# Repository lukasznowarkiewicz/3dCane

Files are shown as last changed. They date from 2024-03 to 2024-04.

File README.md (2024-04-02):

# 3dCane

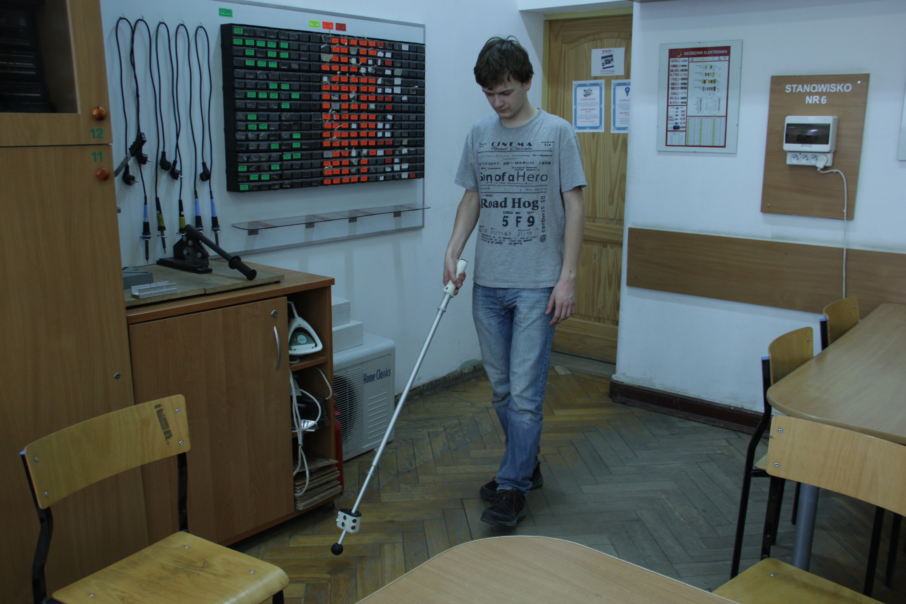
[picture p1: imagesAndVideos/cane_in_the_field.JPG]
3D Cane in the field


## Introduction
In 2017, we, Jacek Martyniak and Łukasz Nowarkiewicz from the Electrical and Electronic School in Szczecin, under the guidance of our mentor with a PhD, Dariusz Mostowski, took on a project for the XVII Innovation and Invention Olympics. Our goal was simple: to design an intelligent electronic cane for the visually impaired and blind. This cane was intended to make navigating both outdoor city environments and indoor spaces easier for them. We focused on ensuring the cane was easy and intuitive to use, with a modular design that could be produced and maintained at a reasonable cost.

## Project assumptions

Our project, 3D.CANE, is built on the foundation of enhancing mobility for the visually impaired through a three-dimensional environmental analysis using a multidirectional ultrasonic scanner. This electronic cane system delivers clear information about potential obstacles and features dual-mode communication (acoustic messages and tactile feedback via vibration) to ensure user safety and convenience. It includes features like fall and assault alarms, time and location updates, and modular design for easy maintenance and upgrades, all while focusing on cost-effective production and user-friendly design.

## Hardware - electronics

The core of the 3D.CANE system is built around two 8-bit AVR ATmega microcontrollers by ATMEL, with the electronic cane module based on an ATmega64 for its advanced capabilities in handling two-way communication with the wrist-worn control module and controlling the ultrasonic scanner module. Essential to the project's functionality, we incorporated various dedicated circuits, including a digital accelerometer (ADXL325), a radio communication module (NRF24L01), vibration motor controllers (BC847 transistors), and distance measuring modules (US-015), all chosen for their reliability and cost-effectiveness. The software was developed in the C language within the Eclipse Indigo environment, emphasizing modular and easily upgradable design.

## Hardware - electronics - 3d.cane 

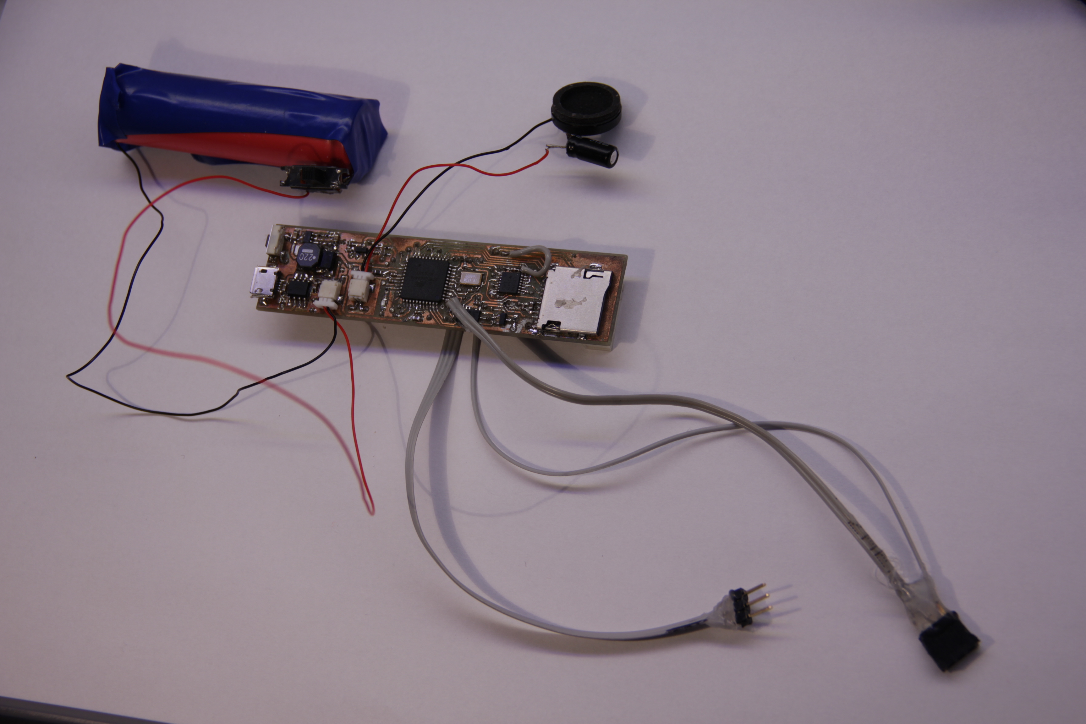
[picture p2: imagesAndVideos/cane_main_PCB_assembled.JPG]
Main PCB Assembled

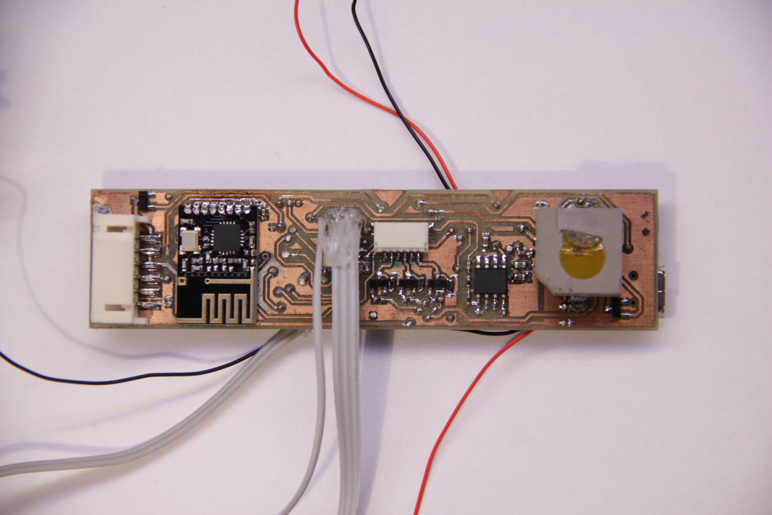
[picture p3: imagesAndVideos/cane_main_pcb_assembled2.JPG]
Main PCB Assembled Alternate View


1. **Power Supply Block:** Utilizes a 3.7V lithium-ion battery type 18650, paired with a compact TP4056 integrated circuit charger, enabling charging via an external adapter through a micro USB port on the handle casing.

2. **Central Processing Unit (CPU):** Heart of the cane, featuring an 8-bit AVR microcontroller by Atmel based on a Reduced Instruction Set Computing (RISC) architecture. This unit, equipped with dual UART interfaces, facilitates programming and communication with the ultrasonic sensors, and possesses picoPower technology for energy efficiency.

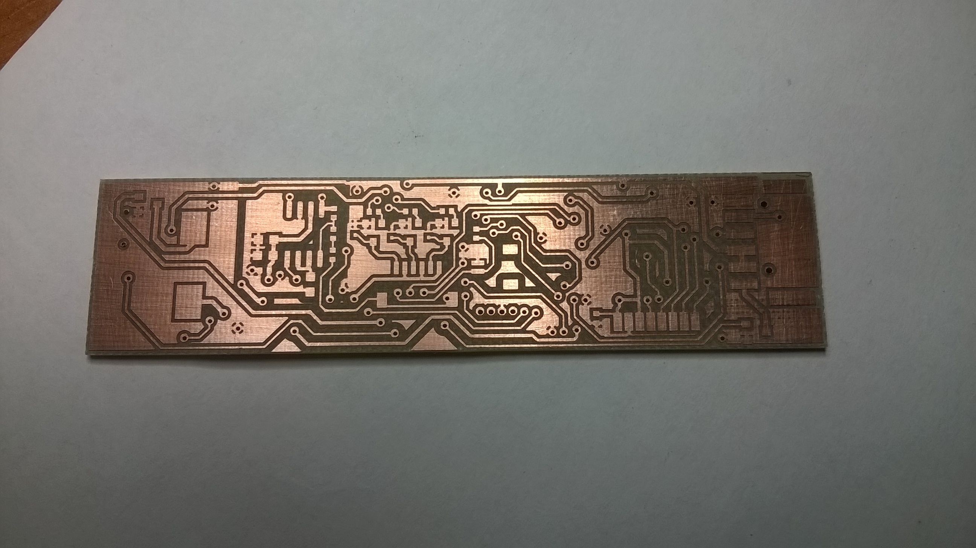
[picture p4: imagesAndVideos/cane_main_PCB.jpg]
Cane Main PCB
   

4. **Ultrasonic Sensor Block:** Employs three US-015 ultrasonic modules for a three-axis environmental scanner, which communicate via trig and echo lines to measure distances using 40 KHz sound waves, and calculates distance based on the time duration of the high state signal.

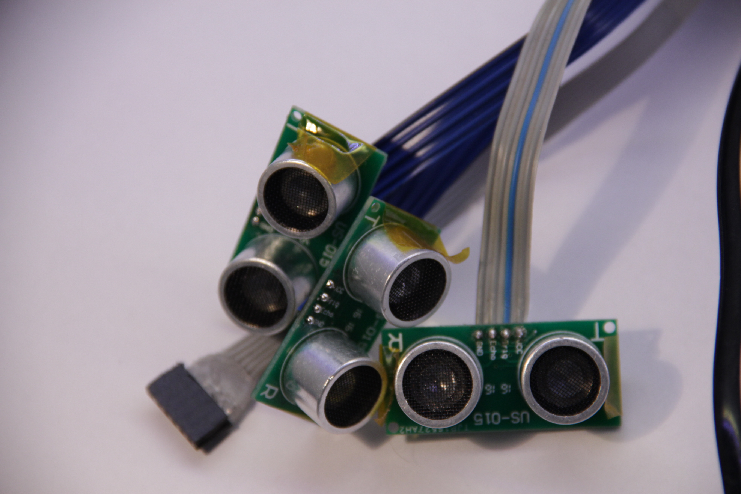
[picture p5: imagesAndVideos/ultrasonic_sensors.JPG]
Ultrasonic Sensors

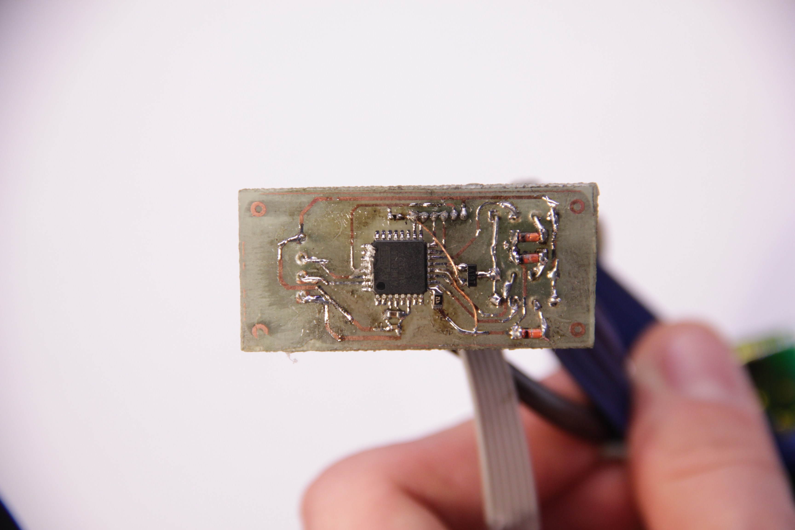
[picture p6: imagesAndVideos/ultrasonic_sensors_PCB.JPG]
Ultrasonic Sensors PCB

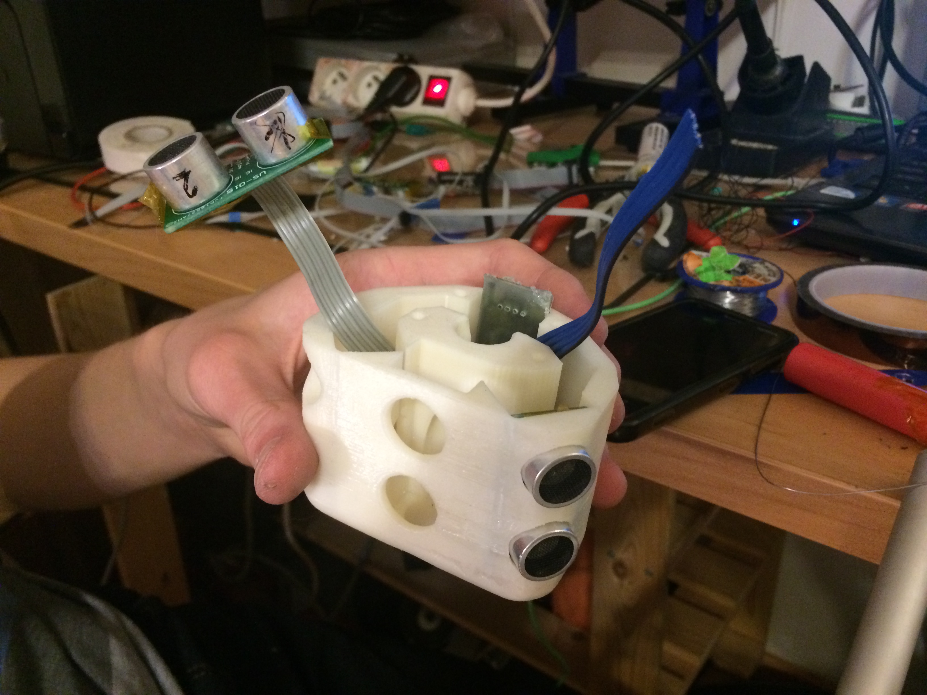
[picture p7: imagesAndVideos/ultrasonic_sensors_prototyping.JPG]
Ultrasonic Sensors Prototyping


4. **Logic Level Conversion Block:** Incorporates a 74LVC125 buffer/converter IC to accommodate devices requiring lower voltage levels than the microcontroller's 5V, including the microSD card, radio communication module, and accelerometer.

5. **Radio Communication Block:** Facilitates wireless interaction between the cane and a wrist-worn device using an nRF24L01 module operating at 2.4GHz, enabling remote activation of the cane's auditory signals for easy location.

6. **Memory Card Slot:** Utilizes a microSD card for storing voice recordings, easily transferable from a computer, providing information such as battery status and charging state.

7. **Accelerometer:** The ADXL345, a 3-axis, high-resolution 13-bit accelerometer, detects falls and improper use by monitoring deviations from vertical alignment, contributing to the user's learning process for correct cane usage.

8. **Audio Block:** Contains a speaker powered by an LM4871 amplifier, providing clear audio communications about battery charge and operational status, with recordings decoded from the microSD card via the microcontroller's PWM signal.

9. **Vibration Motors Block:** Equipped with three vibration motors positioned to indicate obstacle directionality (left, right, or front) to the user, operating in pulsating or continuous modes based on obstacle proximity, powered directly without needing a voltage regulator due to calculated current requirements.

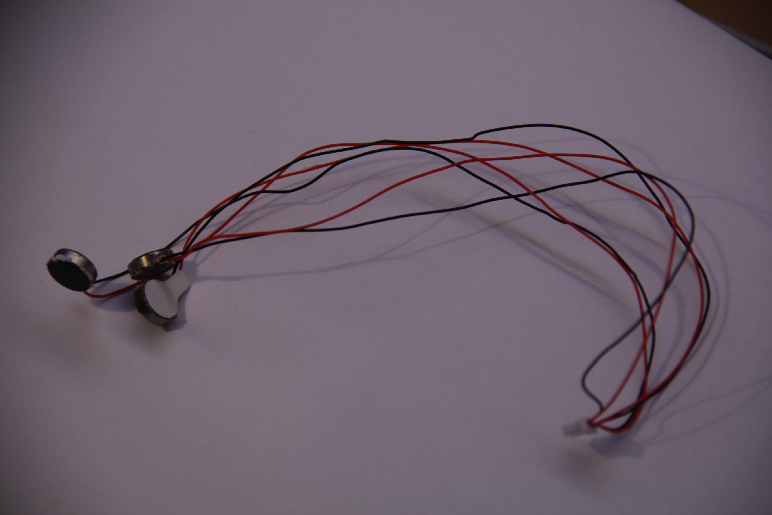
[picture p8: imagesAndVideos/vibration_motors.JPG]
Vibration Motors


This system ensures a robust, interactive aid for visually impaired users, blending complex electronics and intuitive feedback mechanisms to enhance navigation and safety.

## Hardware - electronics - watch

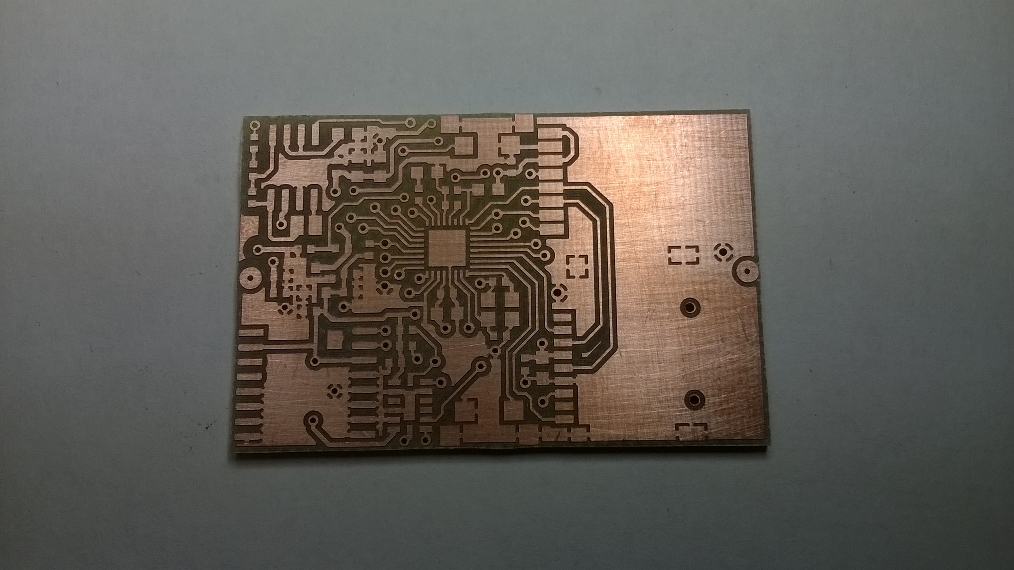
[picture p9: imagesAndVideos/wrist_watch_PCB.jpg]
Wrist Watch PCB

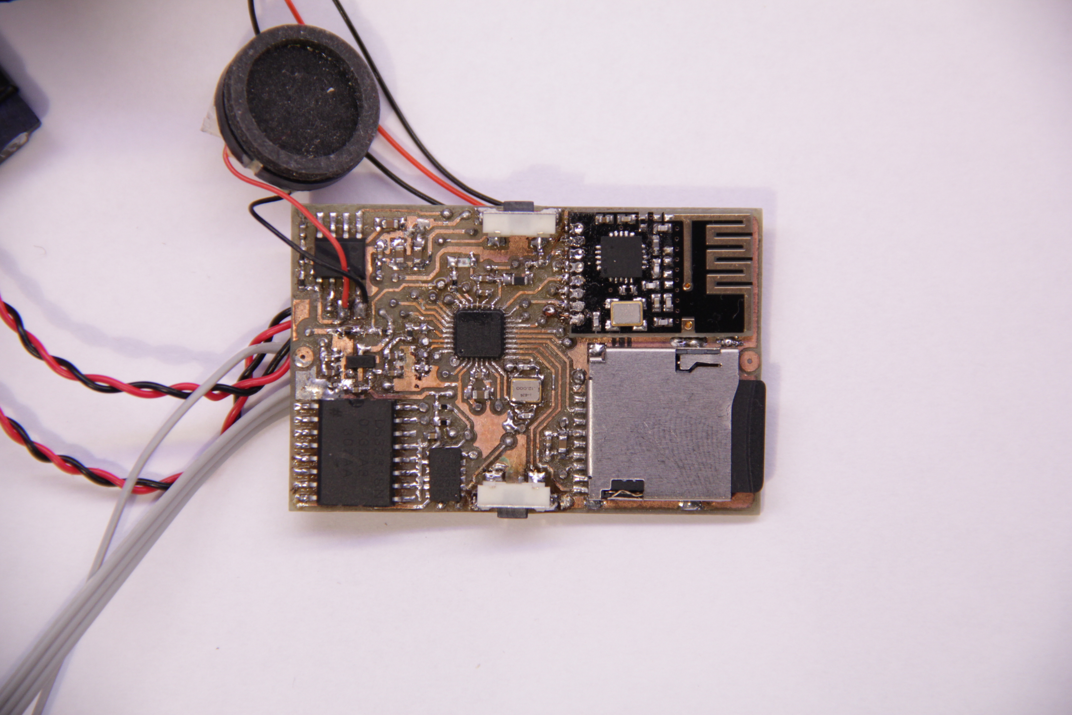
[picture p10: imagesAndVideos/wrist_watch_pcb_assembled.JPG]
Wrist Watch PCB Assembled

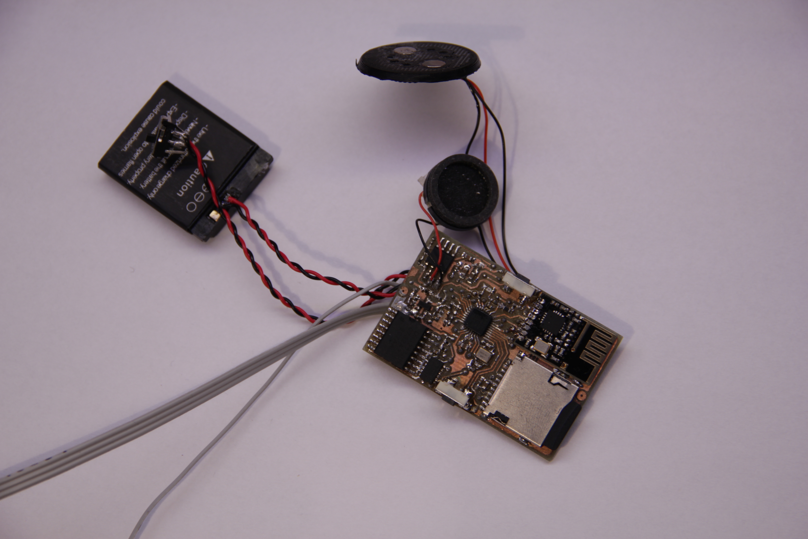
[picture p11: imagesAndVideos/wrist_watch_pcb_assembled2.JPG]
Wrist Watch PCB Assembled2


The wristwatch module is an integral part of our design, functioning as a remote interface for the electronic cane, allowing users to trigger an alarm and access time through voice commands. This module, mirroring the electronic cane's hardware framework, is streamlined for wearable use and comprises seven main functional blocks:

1. **Power Supply Block:** Unlike the cane, the watch uses a smaller, rechargeable YX-S1 battery tailored for smartwatches, featuring a 380mAh capacity and 3.7V nominal voltage with built-in short-circuit and under-voltage protection, ensuring safety and reliability.

2. **Accelerometer:** Employed for dual purposes—detecting falls to initiate an alarm and enabling gesture control to activate the watch's voice functions, such as announcing the time upon a specific arm movement.

3. **Memory Card Slot:** Functions similarly to the cane's, storing voice recordings that include battery status and time announcements, ensuring vital information is readily available to the user.

4. **RTC (Real-Time Clock):** Utilizes the DS3231 integrated circuit for accurate timekeeping, adjusting for temperature variations to maintain precise time. This feature is essential for providing current time updates through voice output.

5. **Central Processing Unit:** Built around the ATmega328P microcontroller, this unit is designed for efficient operation within the compact dimensions of a wristwatch, handling input from buttons, time management, audio playback, and wireless communication with the cane.

6. **Audio Block:** Similar to the cane's audio system but with the amplifier directly powered by the battery, ensuring clear voice playback without the need for voltage level conversion, simplifying the design and maximizing battery efficiency.

7. **Radio Communication Block:** Enables wireless communication with the electronic cane without the need for logic level translation, as both the microcontroller and the nRF24L01 communication module operate at 3.3V, facilitating seamless interaction between the cane and the watch.

This design ethos ensures that the wristwatch module is not only a functional extension of the electronic cane system but also a standalone device capable of providing users with critical information and controls, enhancing the overall utility and accessibility of the system for visually impaired individuals.

## Hardware - mechanics

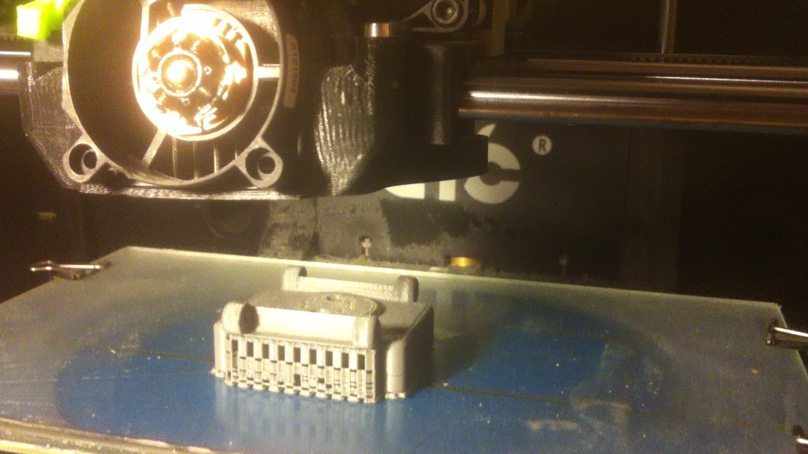
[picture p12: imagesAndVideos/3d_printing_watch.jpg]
3D Printing Watch


The 3D.CANE's mechanical structure, designed in Autodesk Inventor and realized through a combination of 3D printing and aluminum tubing, emphasizes practicality and user adaptability:

1. **Cane Shaft:** Made from aluminum tubes for lightweight strength.
2. **Magnetic Tip Attachment:** Allows for easy swapping of interchangeable tips to match different terrains.
3. **Interchangeable Tips:** Varied designs cater to specific environmental needs.
4. **Ultrasonic Sensor Housing:** Positioned at the cane's lower end for environmental scanning.
5. **Wristwatch Module Casing:** Compact and ergonomic, houses the essential electronic components.

This design strategy ensures the cane is both functional and adaptable, meeting the diverse needs of its users.

## Prototyping and testing

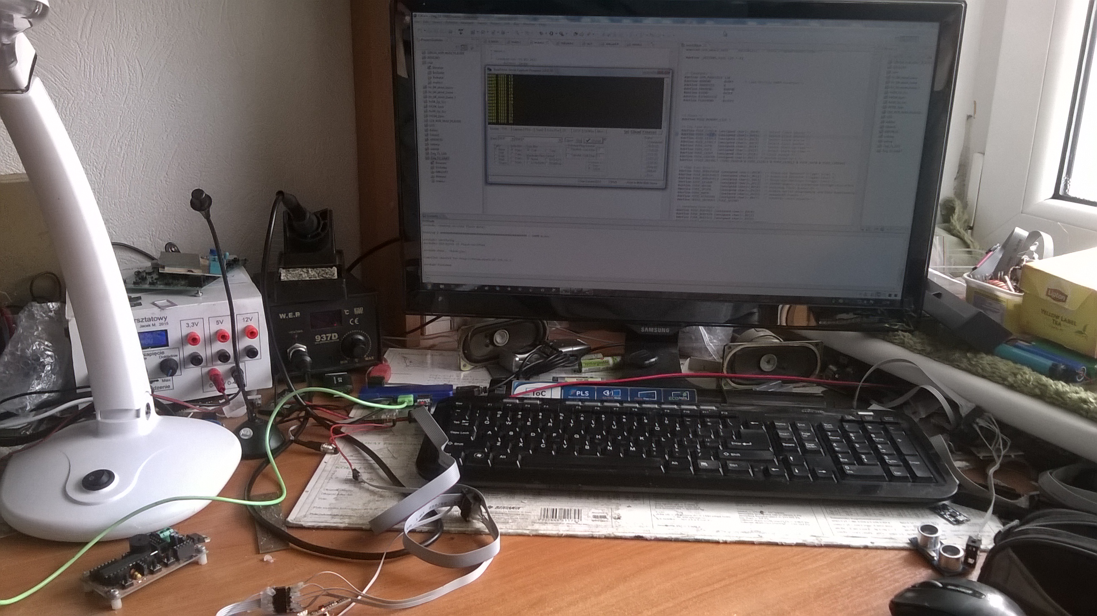
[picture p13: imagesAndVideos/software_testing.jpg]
Software Testing


The development and assembly of the 3D.CANE system involved a meticulous process of prototyping, circuit assembly, case fabrication, and thorough testing of components. 

### 1. System Concept Prototyping
Initial prototyping focused on validating accelerometer functionality and audio playback from a memory card using the Atmel ATB rev. 1.04 development board. This versatile setup minimized the need for a breadboard and extensive wiring, streamlining early testing.

### 2. Printed Circuit Board Assembly
Given the fine traces and small component sizes, PCBs were produced using an LPKF machine, which mechanically mills away excess copper and drills mounting holes. This process was followed by deburring, flux application to prevent corrosion, and manual creation of vias using wire or conductive paste. Both through-hole (THT) and surface-mount (SMT) components were manually soldered using a WEP 937D soldering station and WEP 858D HotAir station.

### 3. Module Casing Fabrication
Module casings for both the cane's handle and the wristwatch were prototyped using 3D printing technology, utilizing ABS and PET plastics for durability and lightweight design. This approach allowed for ergonomic and user-friendly designs to be tested and refined quickly.

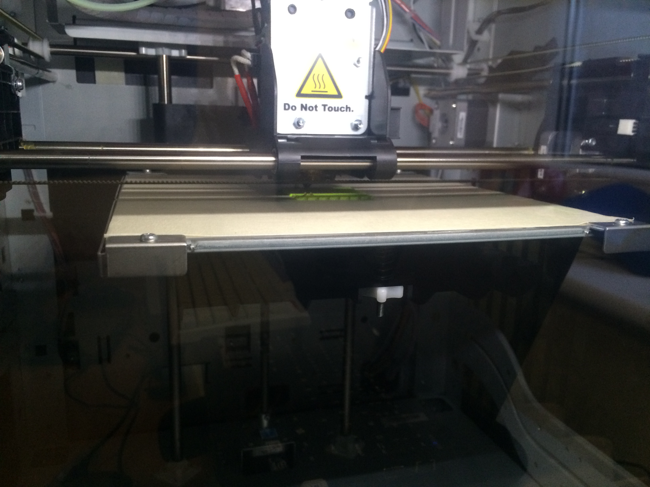
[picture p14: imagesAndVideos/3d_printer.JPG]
3D Printer

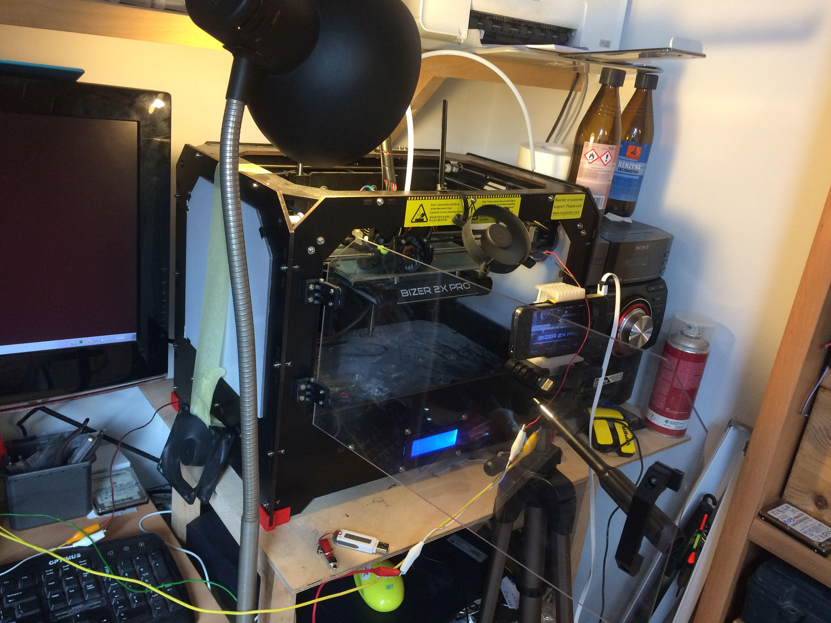
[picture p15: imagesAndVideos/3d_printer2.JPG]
3D Printer2


https://github.com/lukasznowarkiewicz/3dCane/assets/82212257/3fb58380-1fda-4e18-92d1-913e155af232

### 4. Programming and Module Testing
The USBASP programmer was used for flashing the AVR microcontrollers, accommodating the different operating voltages (5V for the cane and 3.3V for the watch) without risking damage to the components. Each device's functionality, including RTC, wireless communication, and other subsystems, was individually verified before integrating them into the complete system.

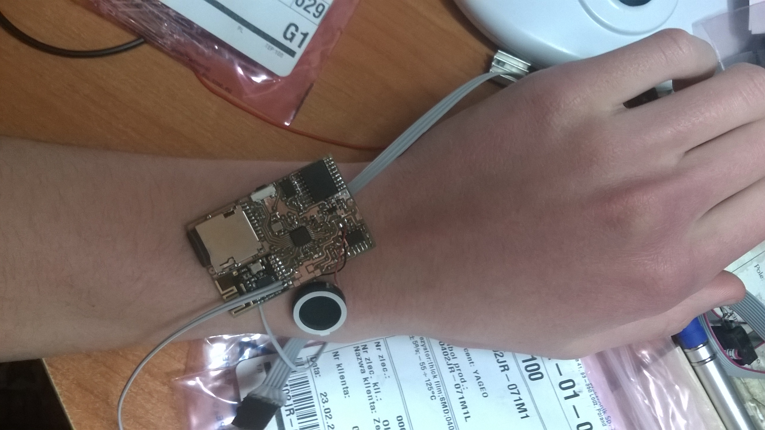
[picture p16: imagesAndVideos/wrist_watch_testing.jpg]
Wrist Watch Testing


https://github.com/lukasznowarkiewicz/3dCane/assets/82212257/31495ac6-1cd3-4608-bdf9-e41c6840ae2c

### Assembly Challenges
Assembling the wristwatch involved attaching charging connectors and magnets, soldering the battery and wiring, fitting the components into the casing, and securing the cover. Assembling the cane was more complex, requiring the aluminum structure assembly, sensor mounting, wiring, and integration of vibratory motors, speaker, and electronic components into the handle.

### Testing and Finalization
Using the mkAVRcalculator software, the microcontrollers in both the cane and watch were detected and programmed. After verifying the operation of individual modules like the RTC and wireless communication unit, the subsystems were integrated into their respective devices, culminating in the final assembly of fully functional prototypes.

## Summary, future work

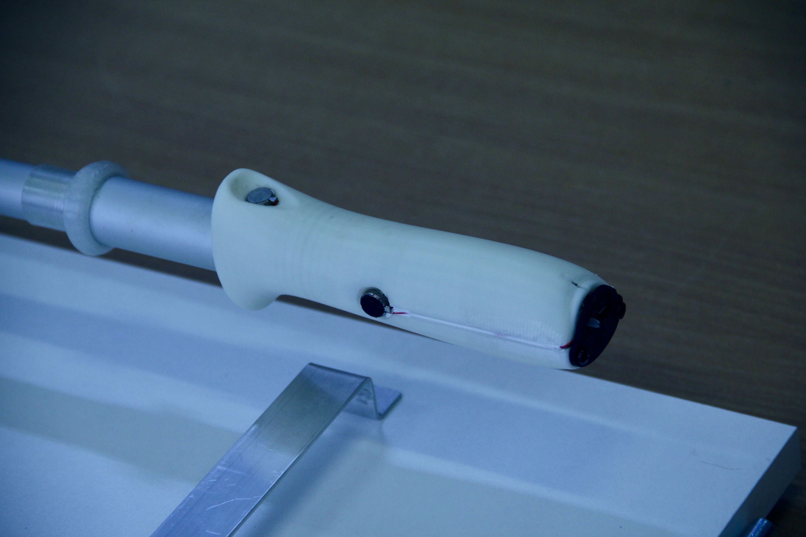
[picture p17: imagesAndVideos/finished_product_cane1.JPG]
Finished Product Cane1

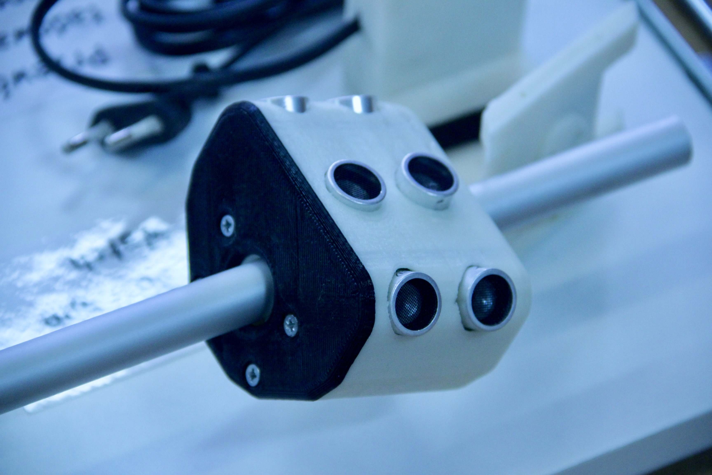
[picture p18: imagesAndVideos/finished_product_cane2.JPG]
Finished Product Cane2

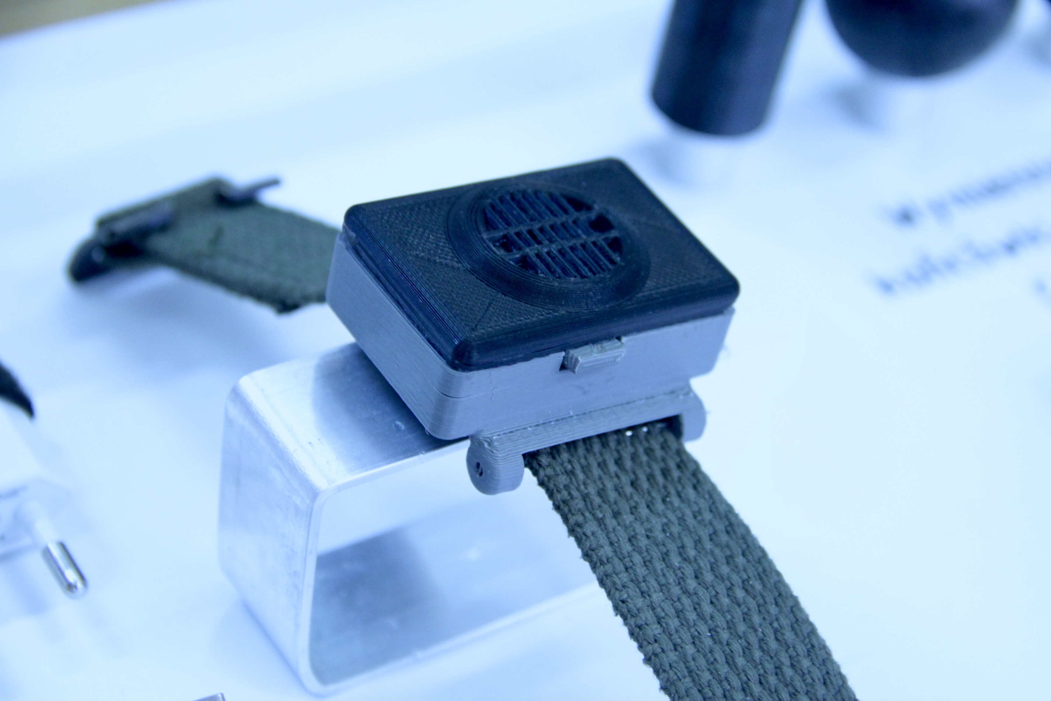
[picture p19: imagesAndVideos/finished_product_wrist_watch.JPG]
Finished Product Wrist Watch


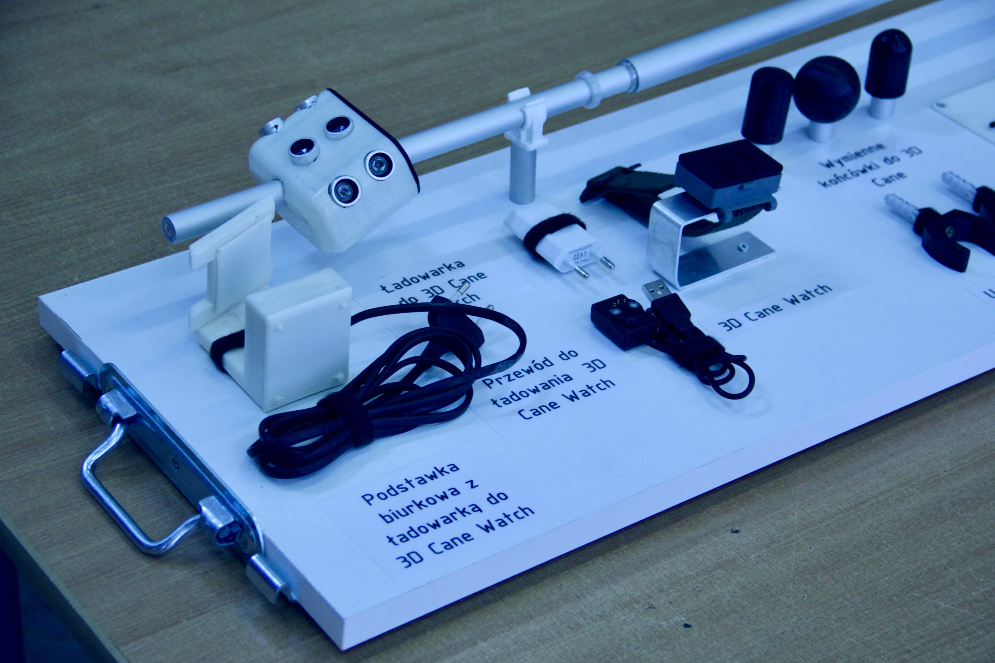
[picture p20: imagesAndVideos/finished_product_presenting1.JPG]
Finished Product Presenting1

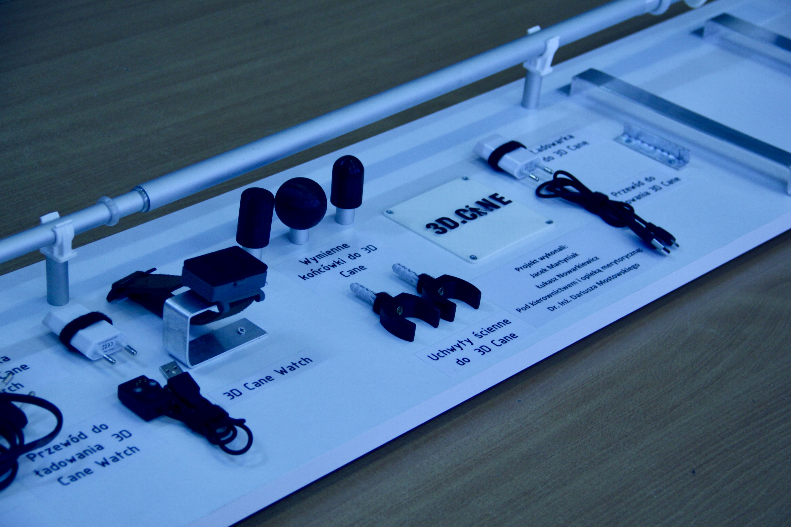
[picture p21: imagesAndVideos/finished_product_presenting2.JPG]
Finished Product Presenting2

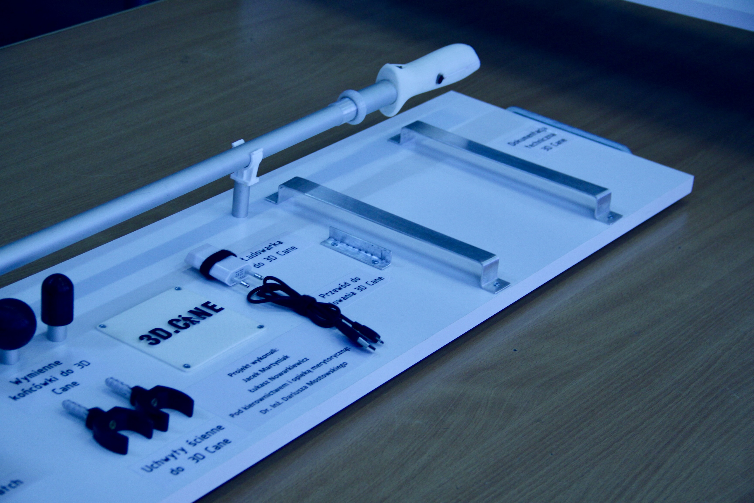
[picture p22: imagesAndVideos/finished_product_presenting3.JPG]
Finished Product Presenting3


The conclusion of the 3D.CANE system development underscores both the achievements and the avenues for future improvements:

### Achievements
- The system successfully integrates an electronic cane and a wristwatch module, enhancing navigational capabilities for visually impaired users.
- The calibration and configuration process is straightforward, allowing users to easily activate and set up both the cane and the watch.
- The prototype demonstrates the practical application of ultrasonic sensors for environment scanning, along with audible and tactile feedback mechanisms.

### Areas for Improvement and Future Work
- **Cane Illumination:** The project did not accomplish the implementation of cane illumination due to the depletion of transparent filament. Adding illumination could enhance visibility and safety during low-light conditions.
- **Sensor Data Processing Speed:** Limited development time impacted the optimization of sensor data processing. Future iterations could focus on enhancing the speed at which sensor data is analyzed and acted upon, improving real-time feedback to users.
- **Communication Range Between the Cane and Watch:** The potential to extend the communication range was not fully explored. Future developments could focus on maximizing the capabilities of the radio module to increase the operational distance between the cane and the wristwatch, enhancing usability and flexibility.

### Next Steps
- **Optimization of Code and Hardware:** Refining the software to process sensor inputs more efficiently and exploring more advanced hardware solutions could significantly improve the system's responsiveness and user experience.
- **Extended Functionality:** Introducing new features, such as GPS navigation or integration with smartphone apps, could provide additional value, making the system even more versatile and user-friendly.
- **User Testing and Feedback:** Conducting extensive user testing with visually impaired individuals will be crucial to identify practical challenges and user needs, guiding further refinements and ensuring the system meets its intended goals effectively.

The 3D.CANE project, while successful in its current form, presents several opportunities for enhancements that could make it an even more valuable aid for the visually impaired community. Continuous development, guided by user feedback and technological advancements, will be key to realizing its full potential.

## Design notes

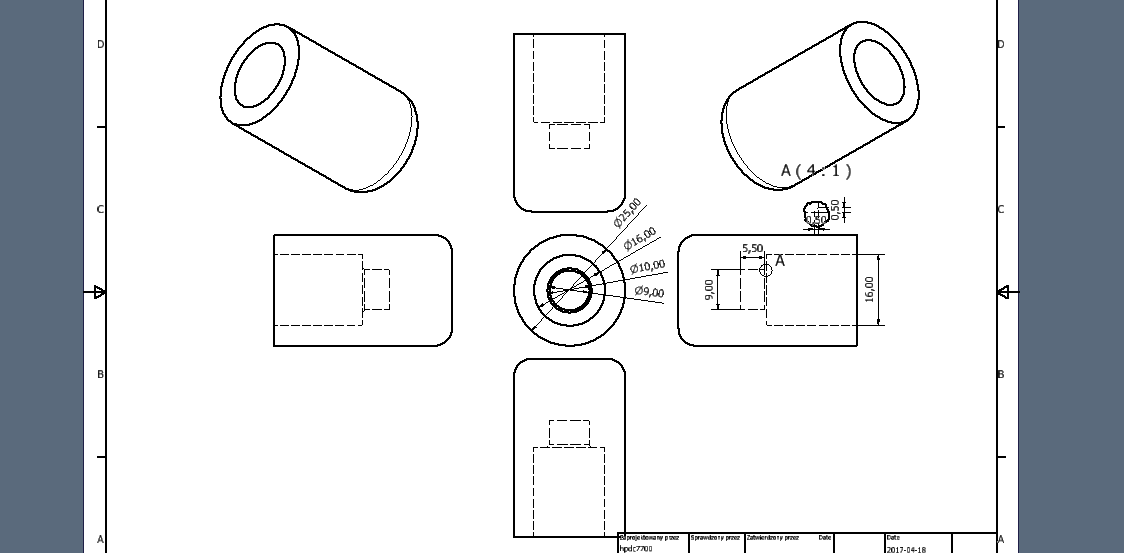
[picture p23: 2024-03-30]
hardware-mechanical/cane/koncowka do laski - walec zaokraglony.png

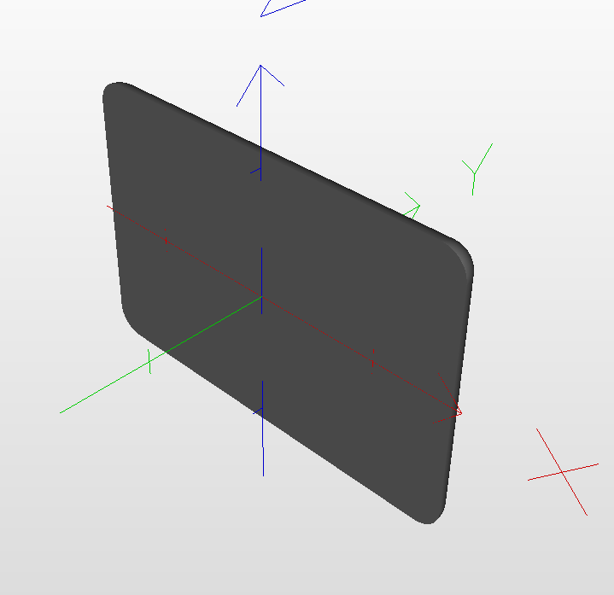
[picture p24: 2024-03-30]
hardware-mechanical/screenshots/Screenshot_9.png

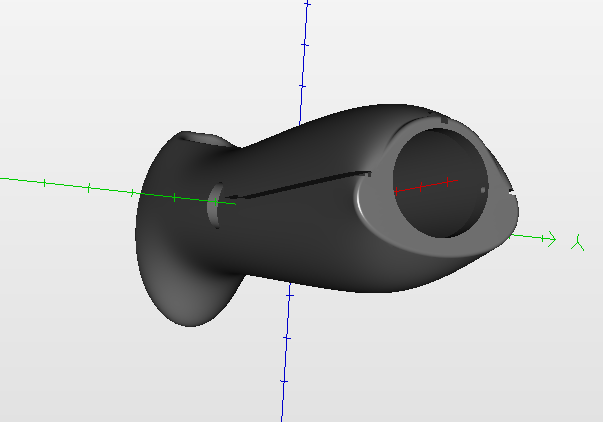
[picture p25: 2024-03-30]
hardware-mechanical/screenshots/Screenshot_14.png

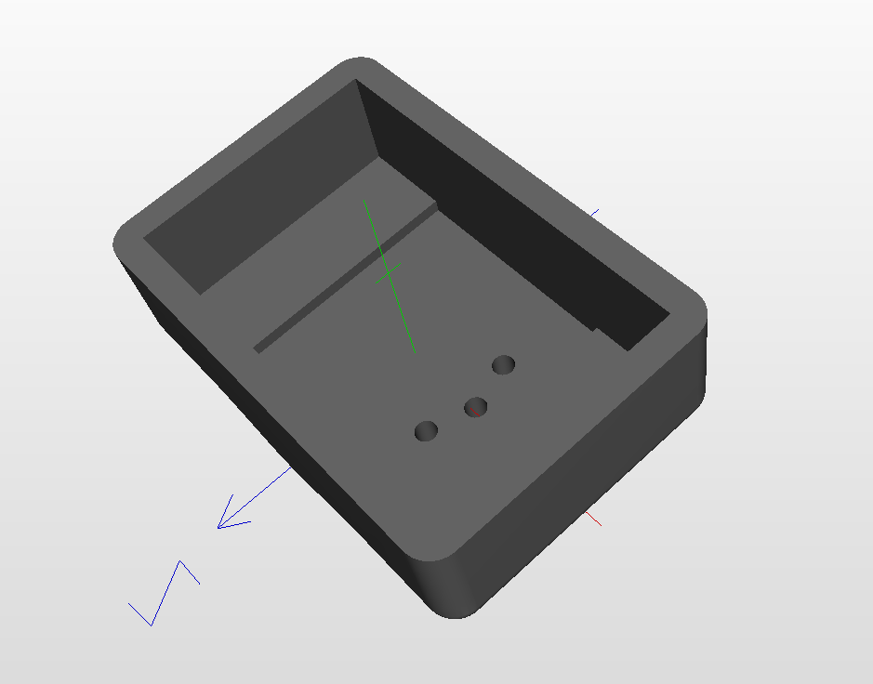
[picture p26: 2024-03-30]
hardware-mechanical/screenshots/Screenshot_11.png

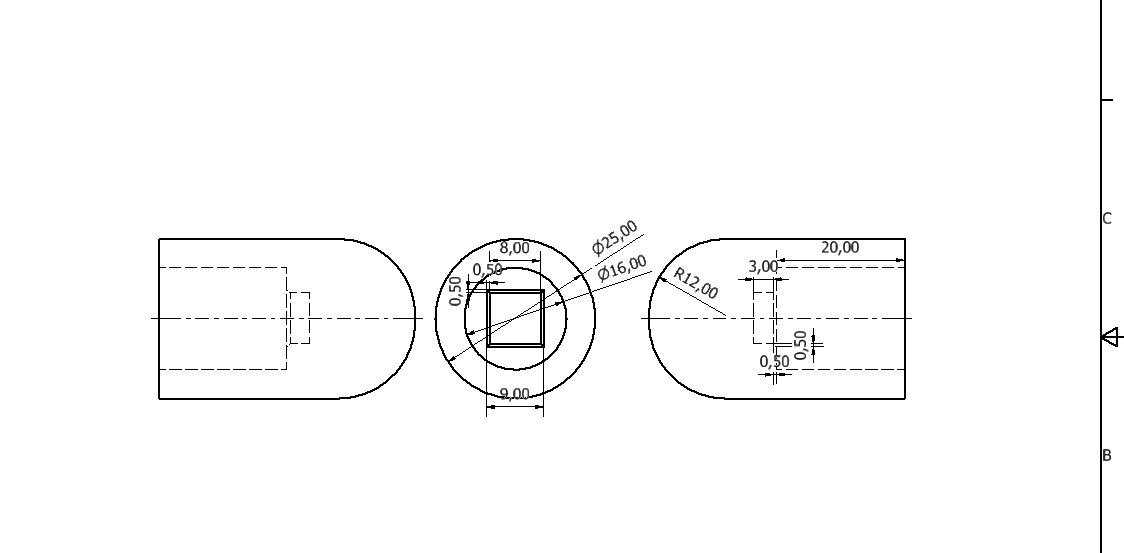
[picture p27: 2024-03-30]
hardware-mechanical/cane/koncowka do laski - zaokraglona.png

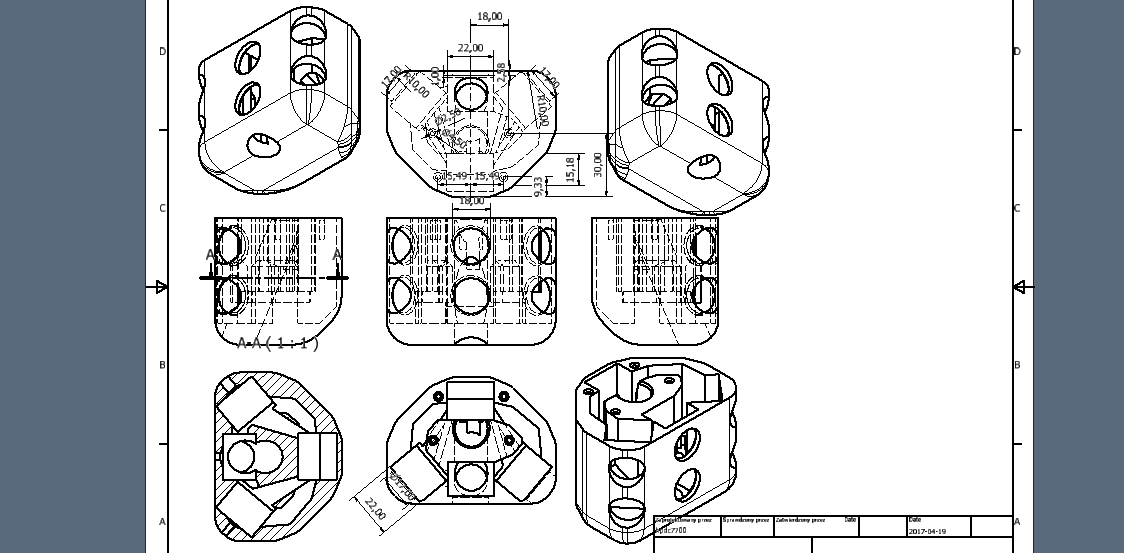
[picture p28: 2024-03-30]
hardware-mechanical/cane/obudowa do czujnikow odleglosci v3,2.png

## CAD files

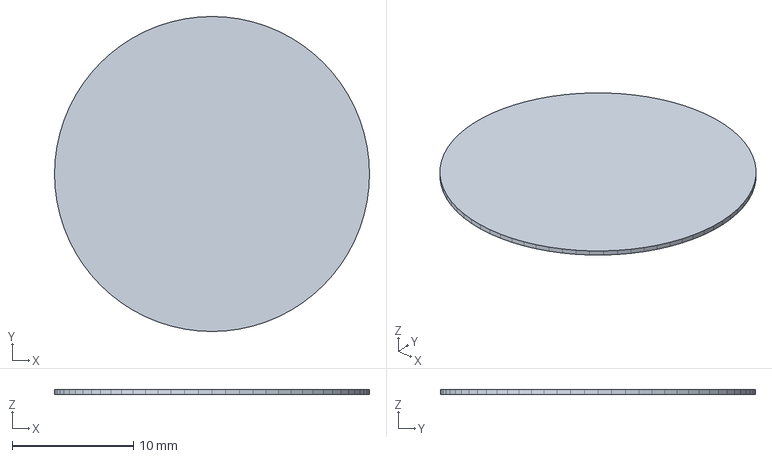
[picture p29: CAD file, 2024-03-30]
hardware-electronics/wrist_watch/zegar_st.step
26.0 x 26.0 x 0.391 mm

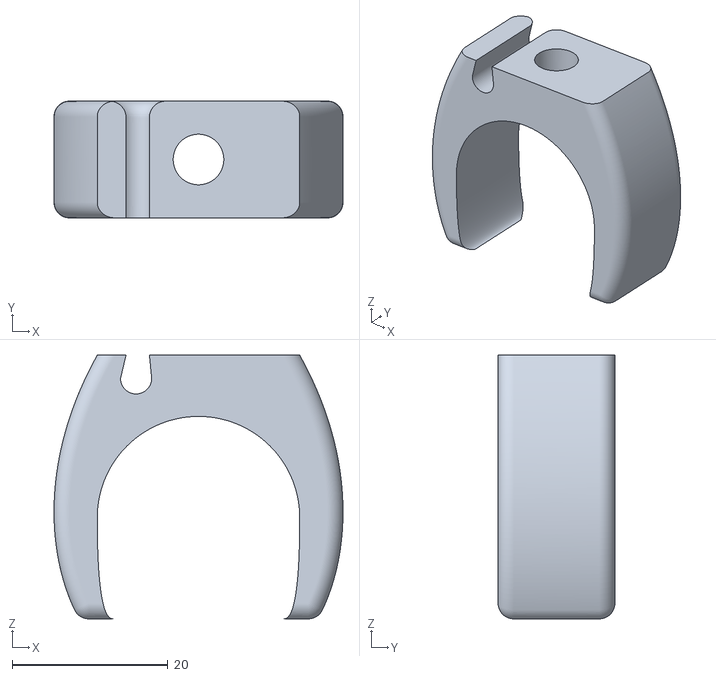
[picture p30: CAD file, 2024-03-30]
hardware-mechanical/accessories/uchwyt scienny do laski z miejscem na przewod do ladowania.stl
37.1 x 15.0 x 33.9

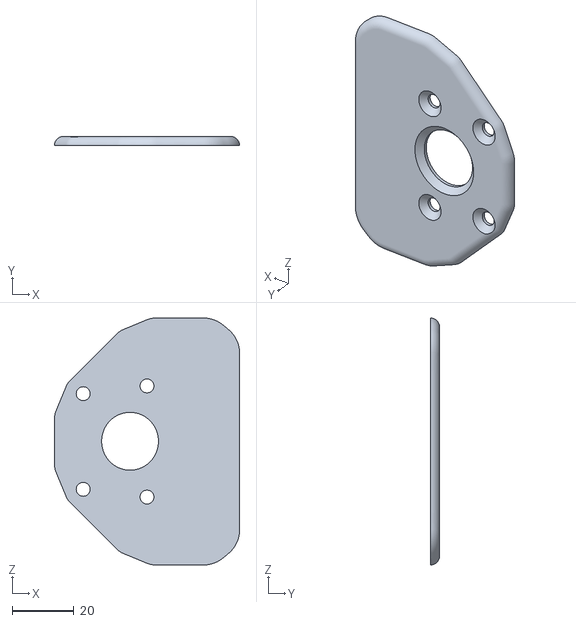
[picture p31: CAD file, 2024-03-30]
hardware-mechanical/cane/obudowa do czujnikow odleglosci v3,2 - przykrywka.stl
60.0 x 3.00 x 80.0

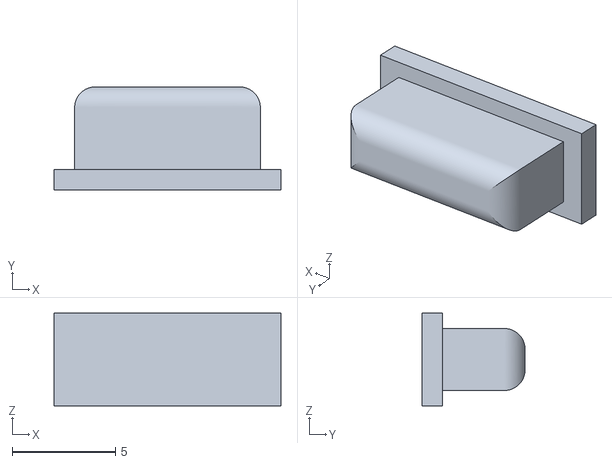
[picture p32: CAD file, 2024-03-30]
hardware-mechanical/watch/PRZYCISK.stl
11.0 x 5.00 x 4.50

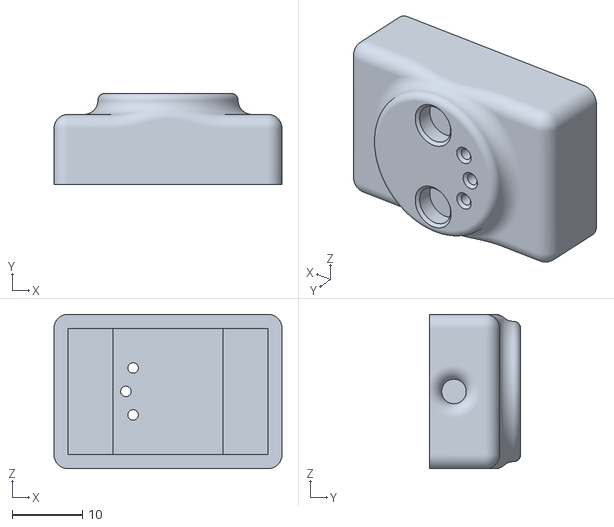
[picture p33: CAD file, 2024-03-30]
hardware-mechanical/accessories/ˆadowarka usb v2.stl
32.5 x 13.0 x 22.0

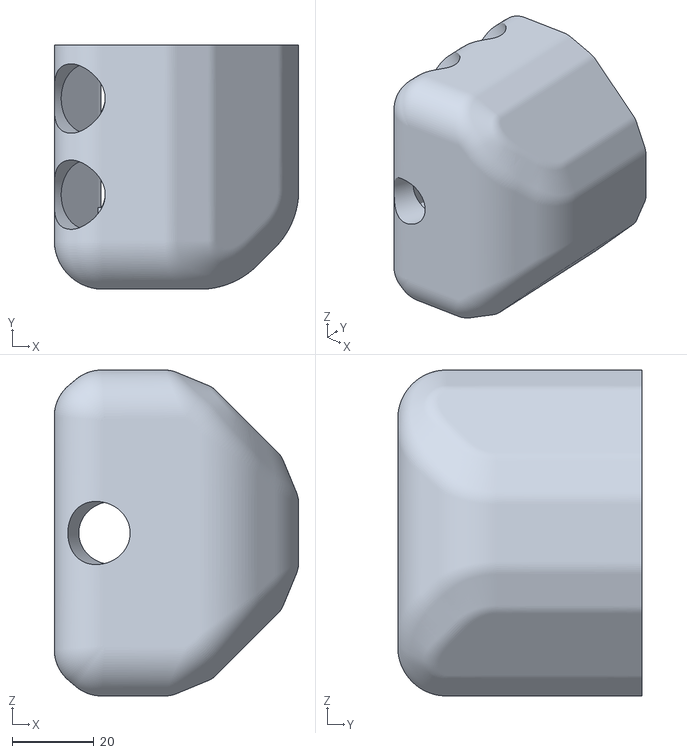
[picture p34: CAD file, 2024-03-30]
hardware-mechanical/cane/obudowa do czujnikow odleglosci v3,3.stl
60.0 x 60.0 x 80.0

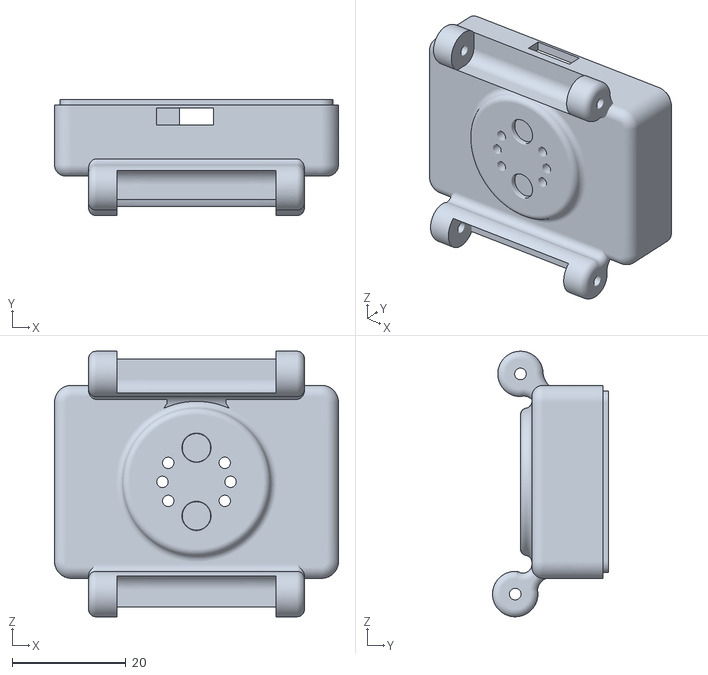
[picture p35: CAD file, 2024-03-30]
hardware-mechanical/watch/obudowa zegarka rev2,3.stl
50.0 x 20.4 x 46.8

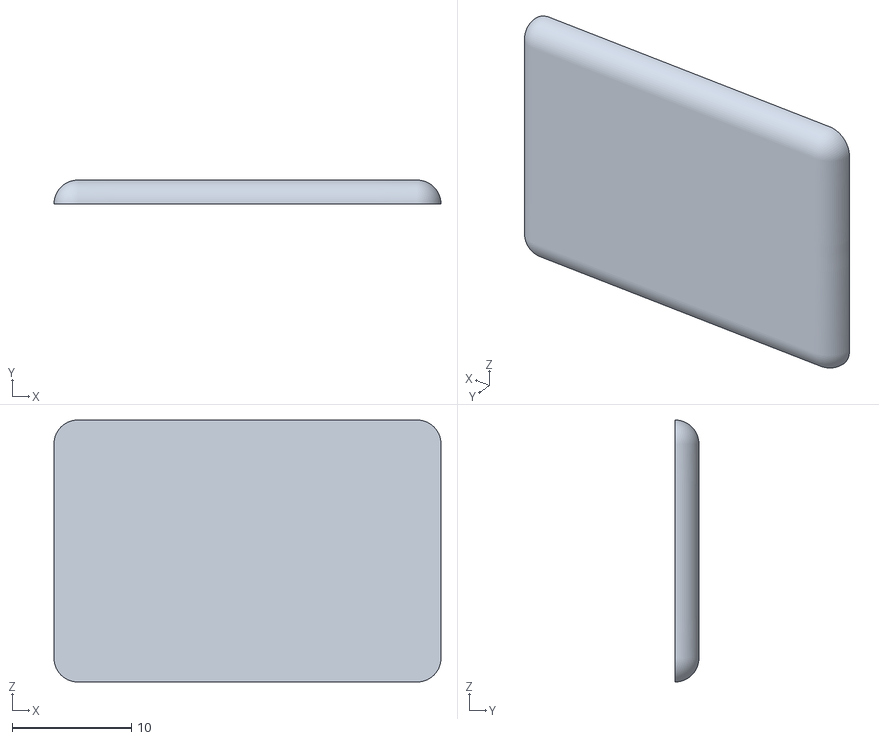
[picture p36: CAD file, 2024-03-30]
hardware-mechanical/accessories/ˆadowarka usb v2 przykrywka.stl
32.5 x 2.00 x 22.0

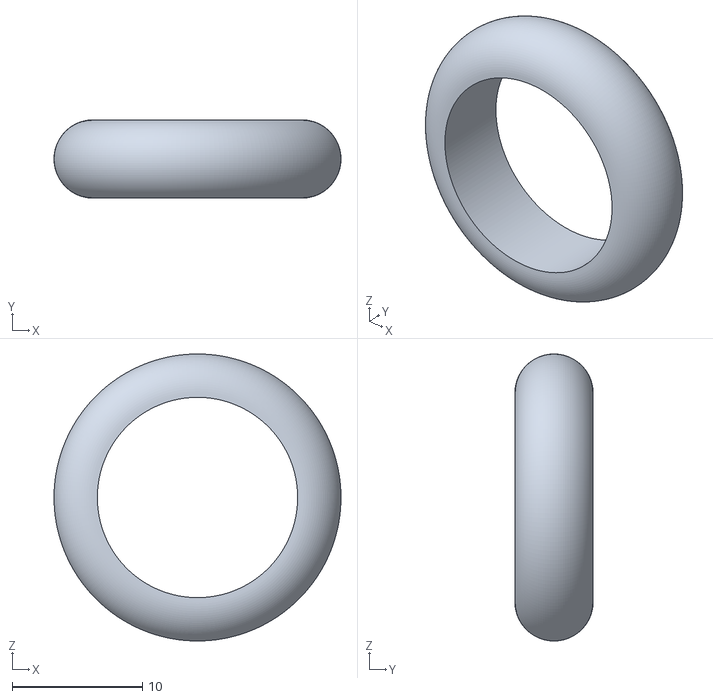
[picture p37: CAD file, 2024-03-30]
hardware-mechanical/cane/pierscien rurka cienka.stl
22.0 x 6.00 x 22.0

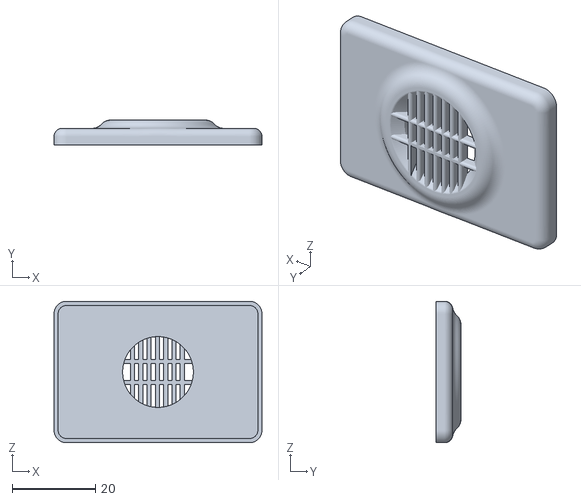
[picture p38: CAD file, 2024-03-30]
hardware-mechanical/watch/obudowa zegarka gขra rev2,2.stl
50.0 x 6.00 x 34.0

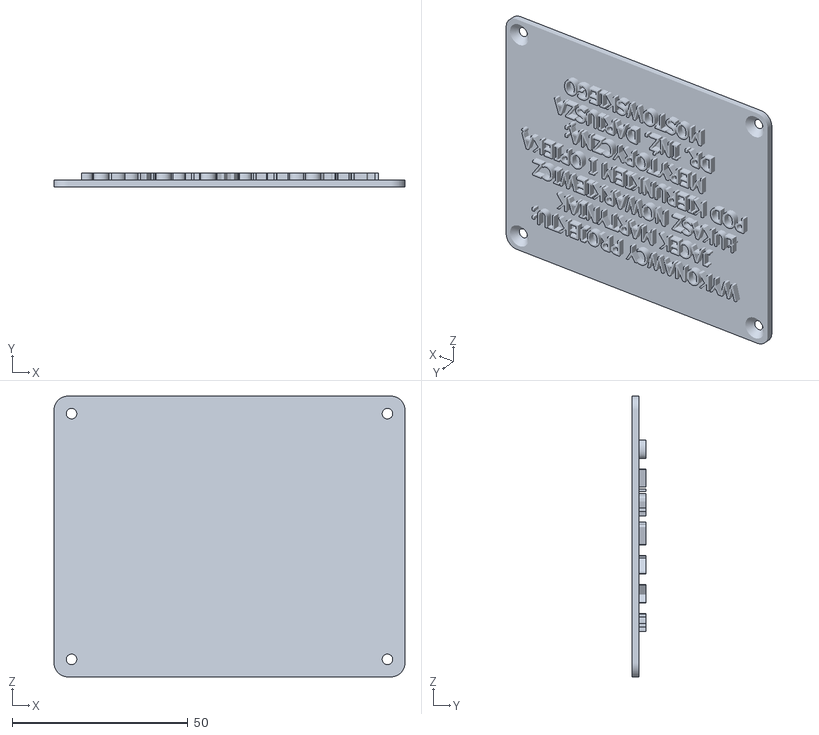
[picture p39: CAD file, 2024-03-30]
hardware-mechanical/accessories/WYKONAWCY.stl
100.0 x 4.00 x 80.0

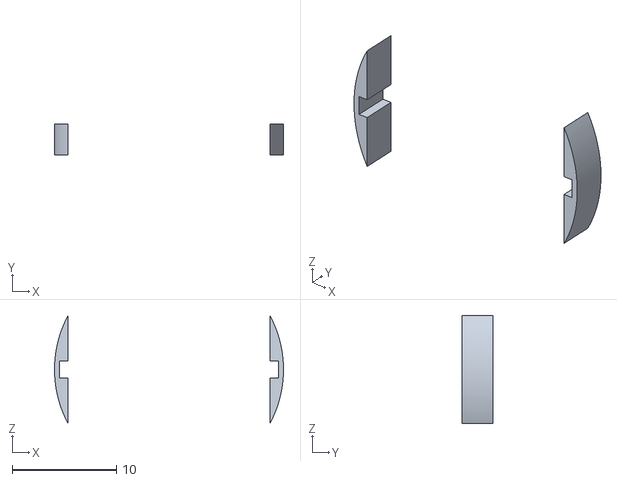
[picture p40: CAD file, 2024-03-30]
hardware-mechanical/cane/TRZYMACZ PCB 3 mm.stl
22.0 x 3.00 x 10.4

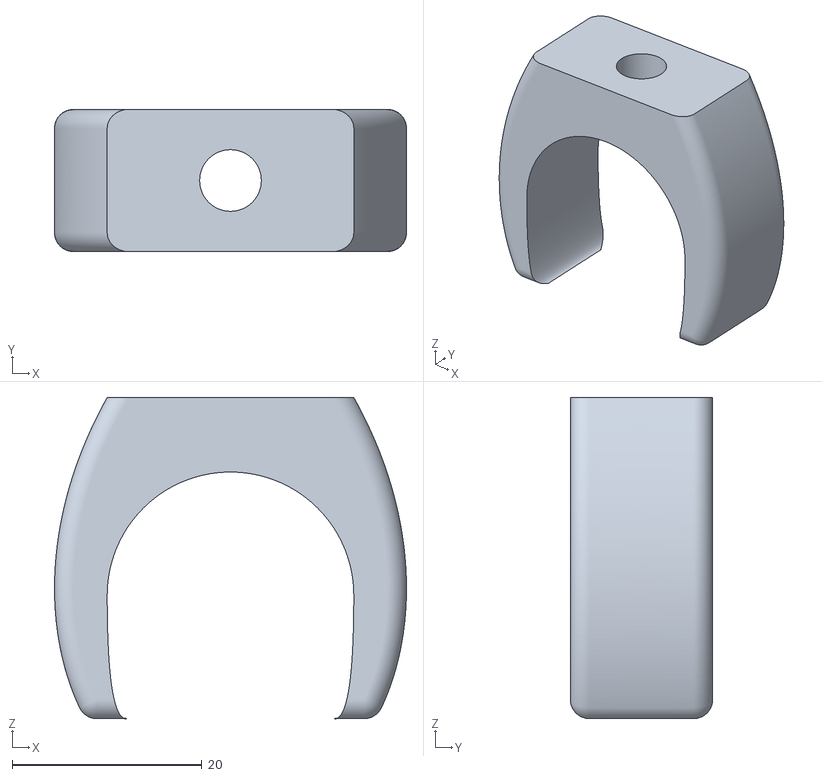
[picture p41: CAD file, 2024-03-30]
hardware-mechanical/accessories/uchwyt scienny do laski.stl
37.1 x 15.0 x 33.9

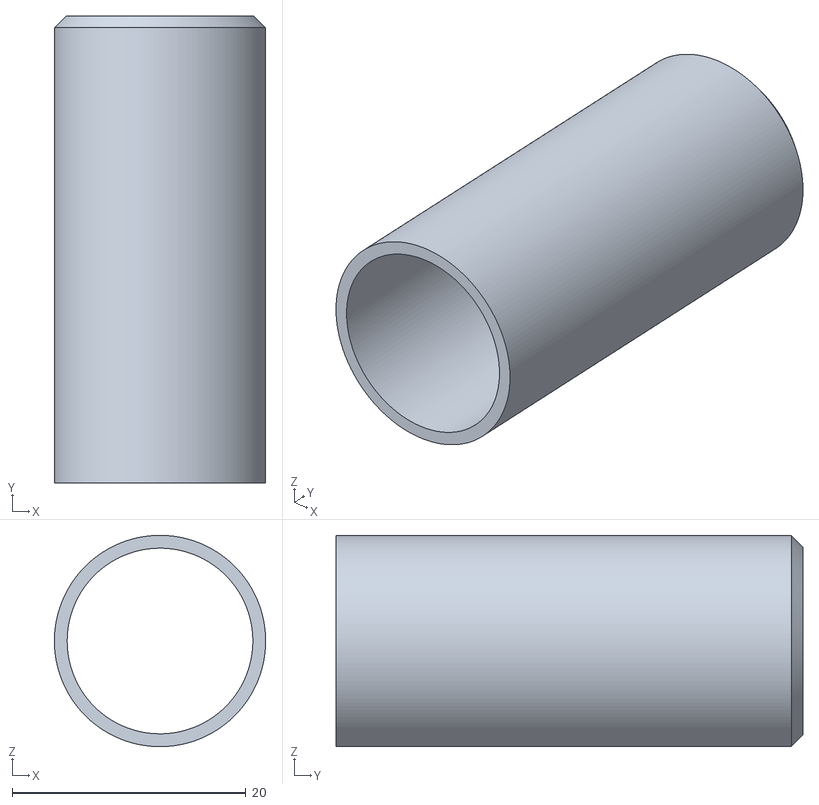
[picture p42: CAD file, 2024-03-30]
hardware-mechanical/cane/pierscien nr 2 srodkowy v2,4.stl
18.1 x 40.0 x 18.1

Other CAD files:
hardware-mechanical/accessories/logo e-laska 1.stl
hardware-mechanical/cane/obudowa do czujnikow odleglosci v3,2.stl
hardware-mechanical/cane/koncowka do laski - walec zaokraglony.stl
hardware-mechanical/cane/raczka do laski ver 5,2.stl
hardware-mechanical/accessories/WYKONAWCY.ipt
hardware-mechanical/accessories/logo e-laska 2.ipt
hardware-mechanical/accessories/uchwyt scienny do laski z miejscem na przewod do ladowania.idw
hardware-mechanical/accessories/uchwyt scienny do laski z miejscem na przewod do ladowania.ipt
hardware-mechanical/accessories/uchwyt scienny do laski.idw
hardware-mechanical/accessories/uchwyt scienny do laski.ipt
hardware-mechanical/accessories/ˆadowarka usb v2 przykrywka.idw
hardware-mechanical/accessories/ˆadowarka usb v2 przykrywka.ipt
hardware-mechanical/accessories/ˆadowarka usb v2-.idw
hardware-mechanical/accessories/ˆadowarka usb v2.ipt
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

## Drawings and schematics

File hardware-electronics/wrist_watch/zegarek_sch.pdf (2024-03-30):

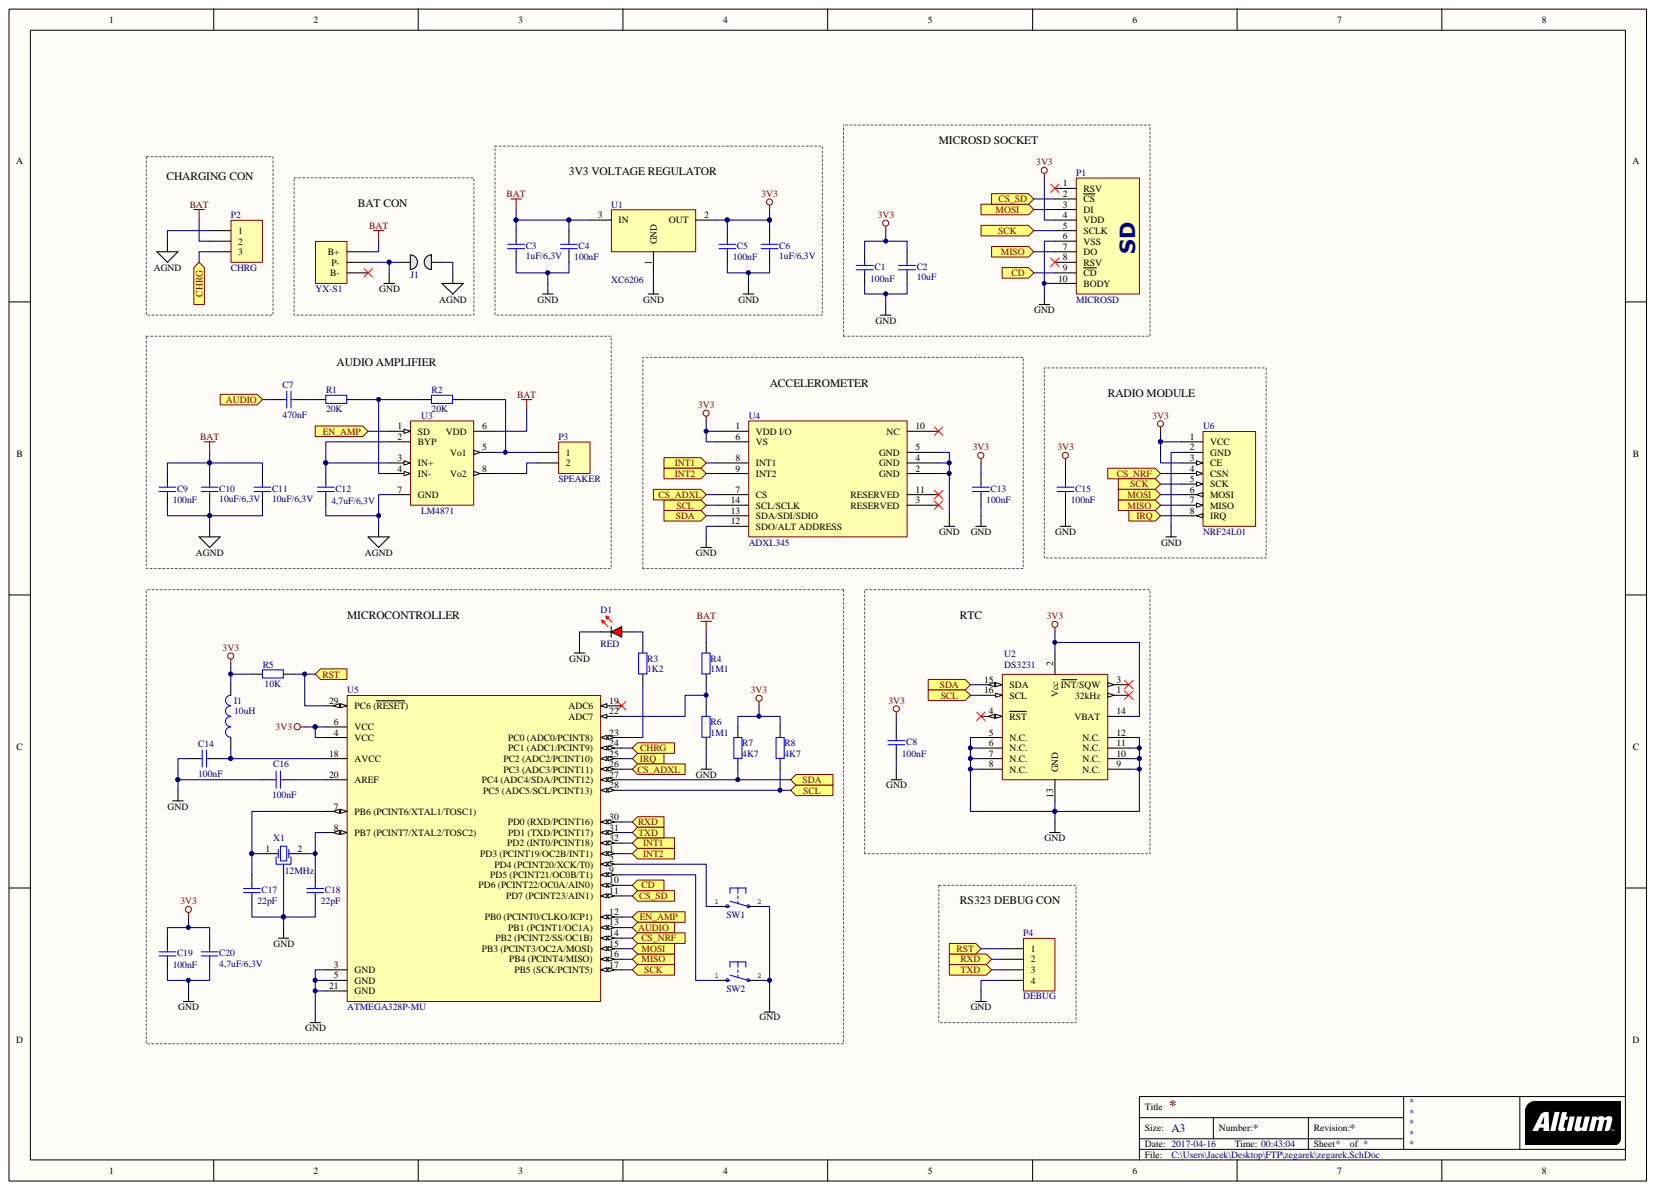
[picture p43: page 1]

Title
C:\Users\Jacek\Desktop\FTP\zegarek\zegarek.SchDoc

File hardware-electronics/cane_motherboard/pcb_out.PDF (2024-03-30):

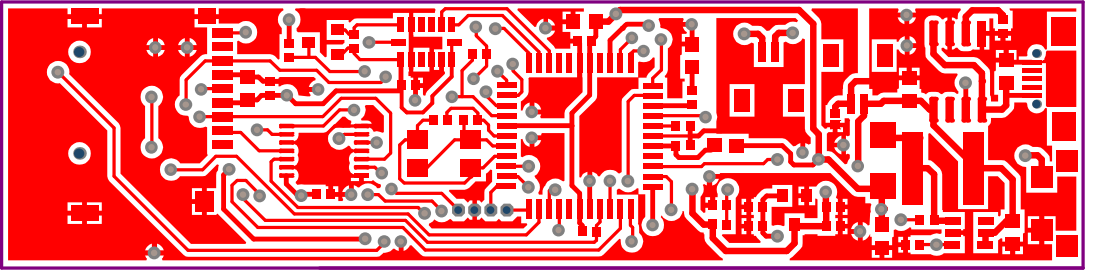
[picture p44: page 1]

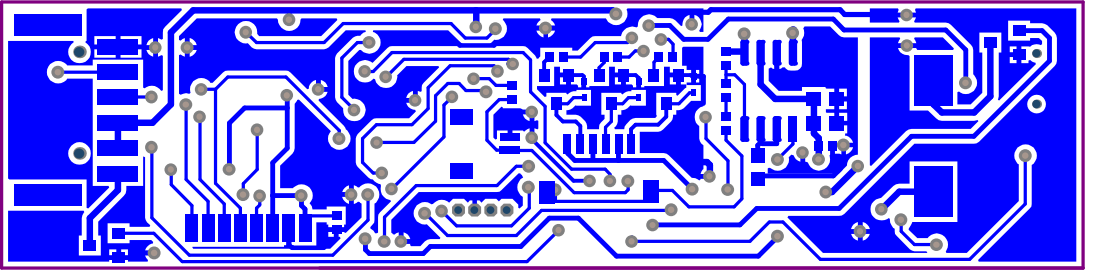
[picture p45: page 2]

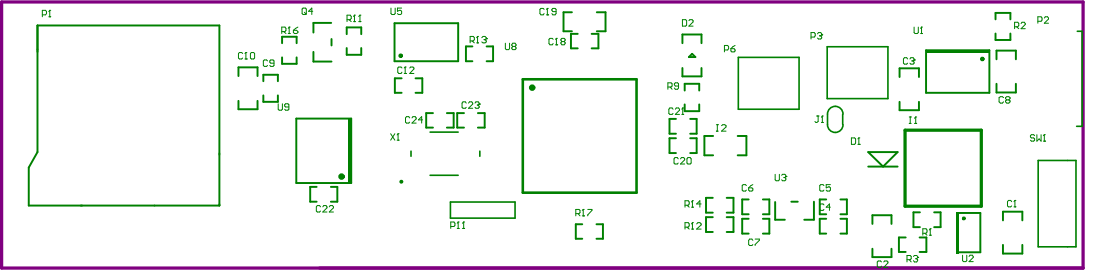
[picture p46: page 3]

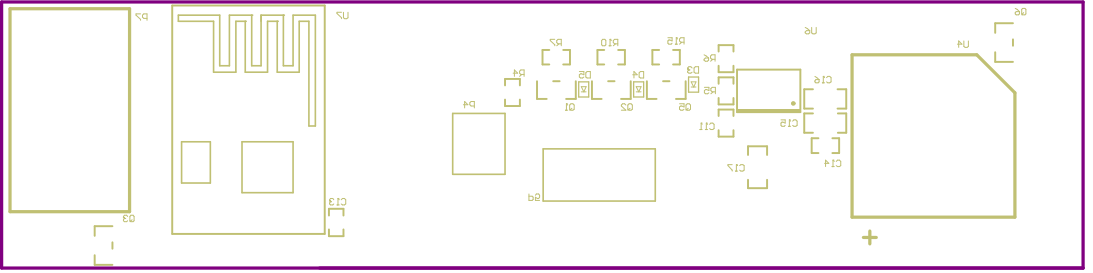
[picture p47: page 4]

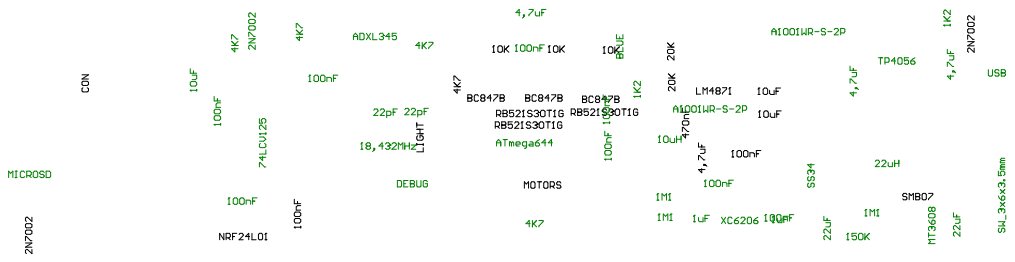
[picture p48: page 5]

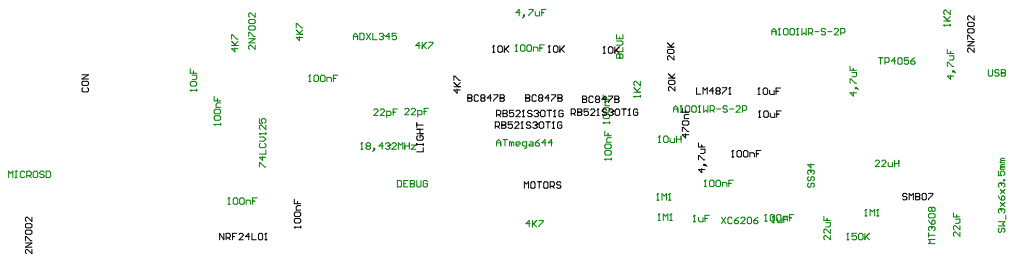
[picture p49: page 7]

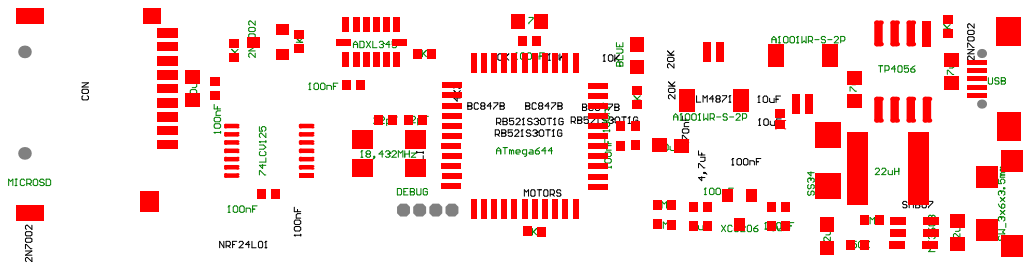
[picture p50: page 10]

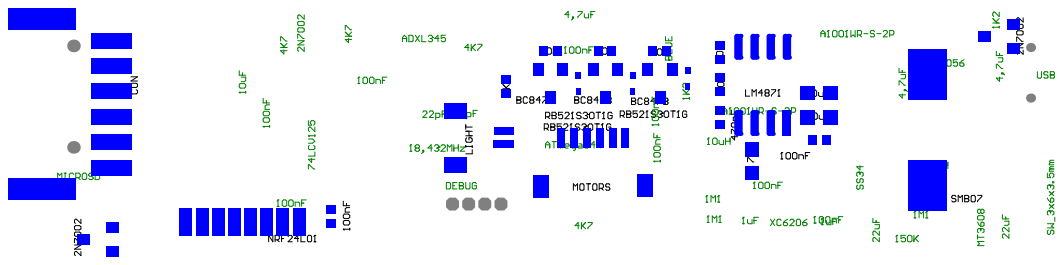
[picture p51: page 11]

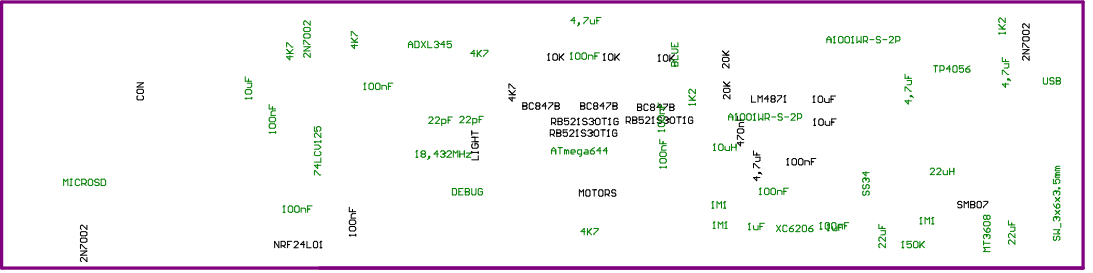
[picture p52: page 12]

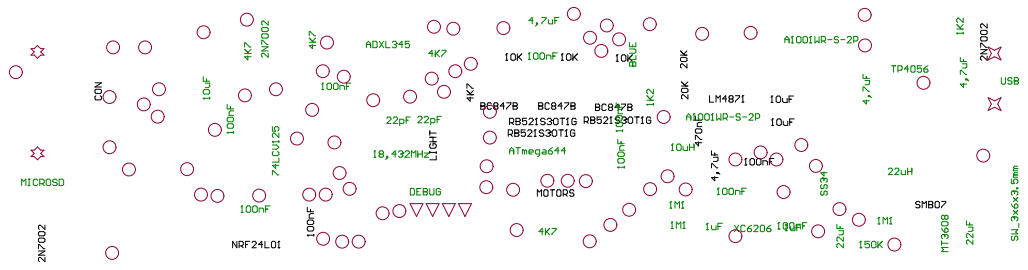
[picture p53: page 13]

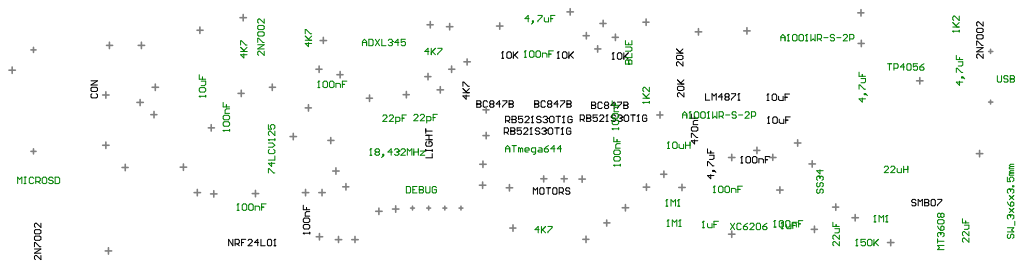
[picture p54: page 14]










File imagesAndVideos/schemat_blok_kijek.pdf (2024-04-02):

Silniki wibracyjne; USB typ C; Wzmacniacz audio

Ultradwikowe
czujniki odlegoci

Karta pamici

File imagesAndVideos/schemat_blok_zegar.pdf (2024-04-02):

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

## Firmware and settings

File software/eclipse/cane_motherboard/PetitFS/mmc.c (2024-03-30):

/*-----------------------------------------------------------------------*/
/* PFF - Low level disk control module for ATtiny85     (C)ChaN, 2009    */
/*-----------------------------------------------------------------------*/

#define _WRITE_FUNC	1

#include <avr/io.h>
#include "diskio.h"



/* Definitions for MMC/SDC command */
#define CMD0	(0x40+0)	/* GO_IDLE_STATE */
#define CMD1	(0x40+1)	/* SEND_OP_COND (MMC) */
#define	ACMD41	(0xC0+41)	/* SEND_OP_COND (SDC) */
#define CMD8	(0x40+8)	/* SEND_IF_COND */
#define CMD16	(0x40+16)	/* SET_BLOCKLEN */
#define CMD17	(0x40+17)	/* READ_SINGLE_BLOCK */
#define CMD24	(0x40+24)	/* WRITE_BLOCK */
#define CMD55	(0x40+55)	/* APP_CMD */
#define CMD58	(0x40+58)	/* READ_OCR */


#define xmit_spi(dat) 	SPDR=(dat); loop_until_bit_is_set(SPSR,SPIF)

static
BYTE rcv_spi (void)
{
	SPDR = 0xFF;
	loop_until_bit_is_set(SPSR, SPIF);
	return SPDR;
}

/* Port Controls (Platform dependent) */
/* Port Controls (Platform dependent) */
#define SELECT()	PORTC &= ~(1<<PC5)		/* MMC CS = L */
#define	DESELECT()	PORTC |=  (1<<PC5)		/* MMC CS = H */
#define	MMC_SEL		!(PORTC &  (1<<PC5))	/* MMC CS status (true:selected) */



/*--------------------------------------------------------------------------

   Module Private Functions

---------------------------------------------------------------------------*/

static
BYTE CardType;


/*-----------------------------------------------------------------------*/
/* Deselect the card and release SPI bus                                 */
/*-----------------------------------------------------------------------*/

static
void release_spi (void)
{
	DESELECT();
	rcv_spi();
}


/*-----------------------------------------------------------------------*/
/* Send a command packet to MMC                                          */
/*-----------------------------------------------------------------------*/

static
BYTE send_cmd (
	BYTE cmd,		/* Command byte */
	DWORD arg		/* Argument */
)
{
	BYTE n, res;


	if (cmd & 0x80) {	/* ACMD<n> is the command sequense of CMD55-CMD<n> */
		cmd &= 0x7F;
		res = send_cmd(CMD55, 0);
		if (res > 1) return res;
	}

	/* Select the card */
	DESELECT();
	rcv_spi();
	SELECT();
	rcv_spi();

	/* Send a command packet */
	xmit_spi(cmd);						/* Start + Command index */
	xmit_spi((BYTE)(arg >> 24));		/* Argument[31..24] */
	xmit_spi((BYTE)(arg >> 16));		/* Argument[23..16] */
	xmit_spi((BYTE)(arg >> 8));			/* Argument[15..8] */
	xmit_spi((BYTE)arg);				/* Argument[7..0] */
	n = 0x01;							/* Dummy CRC + Stop */
	if (cmd == CMD0) n = 0x95;			/* Valid CRC for CMD0(0) */
	if (cmd == CMD8) n = 0x87;			/* Valid CRC for CMD8(0x1AA) */
	xmit_spi(n);

	/* Receive a command response */
	n = 10;								/* Wait for a valid response in timeout of 10 attempts */
	do {
		res = rcv_spi();
	} while ((res & 0x80) && --n);

	return res;			/* Return with the response value */
}



/*--------------------------------------------------------------------------

   Public Functions

---------------------------------------------------------------------------*/


/*-----------------------------------------------------------------------*/
/* Initialize Disk Drive                                                 */
/*-----------------------------------------------------------------------*/

DSTATUS disk_initialize (void)
{
	BYTE n, cmd, ty, ocr[4];
	WORD tmr;

#if _WRITE_FUNC
	if (MMC_SEL) disk_writep(0, 0);		/* Finalize write process if it is in progress */
#endif
	for (n = 100; n; n--) rcv_spi();	/* Dummy clocks */


	ty = 0;
	if (send_cmd(CMD0, 0) == 1) {			/* Enter Idle state */
		if (send_cmd(CMD8, 0x1AA) == 1) {	/* SDv2 */
			for (n = 0; n < 4; n++) ocr[n] = rcv_spi();		/* Get trailing return value of R7 resp */
			if (ocr[2] == 0x01 && ocr[3] == 0xAA) {				/* The card can work at vdd range of 2.7-3.6V */
				for (tmr = 12000; tmr && send_cmd(ACMD41, 1UL << 30); tmr--) ;	/* Wait for leaving idle state (ACMD41 with HCS bit) */
				if (tmr && send_cmd(CMD58, 0) == 0) {		/* Check CCS bit in the OCR */
					for (n = 0; n < 4; n++) ocr[n] = rcv_spi();
					ty = (ocr[0] & 0x40) ? CT_SD2 | CT_BLOCK : CT_SD2;	/* SDv2 (HC or SC) */
				}
			}
		} else {							/* SDv1 or MMCv3 */
			if (send_cmd(ACMD41, 0) <= 1) 	{
				ty = CT_SD1; cmd = ACMD41;	/* SDv1 */
			} else {
				ty = CT_MMC; cmd = CMD1;	/* MMCv3 */
			}
			for (tmr = 25000; tmr && send_cmd(cmd, 0); tmr--) ;	/* Wait for leaving idle state */
			if (!tmr || send_cmd(CMD16, 512) != 0)			/* Set R/W block length to 512 */
				ty = 0;
		}
	}
	CardType = ty;
	release_spi();

	return ty ? 0 : STA_NOINIT;
}



/*-----------------------------------------------------------------------*/
/* Read partial sector                                                   */
/*-----------------------------------------------------------------------*/

DRESULT disk_readp (
	BYTE *buff,		/* Pointer to the read buffer (NULL:Read bytes are forwarded to the stream) */
	DWORD lba,		/* Sector number (LBA) */
	WORD ofs,		/* Byte offset to read from (0..511) */
	WORD cnt		/* Number of bytes to read (ofs + cnt mus be <= 512) */
)
{
	DRESULT res;
	BYTE rc;
	WORD bc;


	if (!(CardType & CT_BLOCK)) lba *= 512;		/* Convert to byte address if needed */

	res = RES_ERROR;
	if (send_cmd(CMD17, lba) == 0) {		/* READ_SINGLE_BLOCK */

		bc = 30000;
		do {							/* Wait for data packet in timeout of 100ms */
			rc = rcv_spi();
		} while (rc == 0xFF && --bc);

		if (rc == 0xFE) {				/* A data packet arrived */
			bc = 514 - ofs - cnt;

			/* Skip leading bytes */
			if (ofs) {
				do rcv_spi(); while (--ofs);
			}

			/* Receive a part of the sector */
			if (buff) {	/* Store data to the memory */
				do
					*buff++ = rcv_spi();
				while (--cnt);
			}

			/* Skip trailing bytes and CRC */
			do rcv_spi(); while (--bc);

			res = RES_OK;
		}
	}

	release_spi();

	return res;
}



/*-----------------------------------------------------------------------*/
/* Write partial sector                                                  */
/*-----------------------------------------------------------------------*/
#if _WRITE_FUNC
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

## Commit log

2024-03-30 Added hardware-electronics
    [PCB_Project1.PrjPCB, kijek.PcbDoc, kijek.PrjPcb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]
2024-03-30 Added schematic in PDF
2024-03-30 Added hardware-mechanical
    [PRZYCISK.ipt, PRZYCISK.stl, TRZYMACZ PCB 10 mm.stl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]
